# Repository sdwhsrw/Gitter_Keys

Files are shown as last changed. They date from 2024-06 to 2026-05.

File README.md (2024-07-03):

# Warning: The project is still in progress.
# The project code and design files have not yet been organized and uploaded.

# Gitter_Keys
Gitter is an open-source key matrix project. Gitter_Keys is the mechanical keys key version of it. 

Gitter is designed to easy build. 
It uses raspberry pi pico as controller, which you can easily get with 4 to 5 Euros
The smd components are easy to solder even for beginner. 

# BOM

# Building guide
to be continue

79f692e05d4cde133819e3d3e140f79

# Links

https://www.instagram.com/wqnmf2046/

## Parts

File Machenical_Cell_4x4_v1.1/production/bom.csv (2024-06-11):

Designator | Footprint | Quantity | Value | LCSC Part #
D1, D10, D11, D12, D13, D14, D15, D16, D2, D3, D4, D5, D6, D7, D8, D9 | D_MiniMELF | 16 | LL4148
H1, H2, H3, H4 | Moutinghole_M2.5 | 4 | MountingHole
J1, J10, J11, J12, J13, J14, J15, J16, J17, J18, J19, J2, J20, J21, J22, J23, J24, J3, J4, J5, J6, J7, J8, J9 | SolderPad_2 | 24 | Conn_01x02_Pin
J25 | PinHeader_1x06_P2.54mm_Vertical | 1 | Conn_01x06_Pin
K1, K10, K11, K12, K13, K14, K15, K16, K2, K3, K4, K5, K6, K7, K8, K9 | MX-Hotswap-1U-1206-Reserved-LED | 16 | CherryMX_LED
Pico1 | Pico_THR_Necessary | 1 | Pico_Necessary
R1, R10, R11, R12, R13, R14, R15, R16, R2, R3, R4, R5, R6, R7, R8, R9 | 0805 | 16 | LED_Res

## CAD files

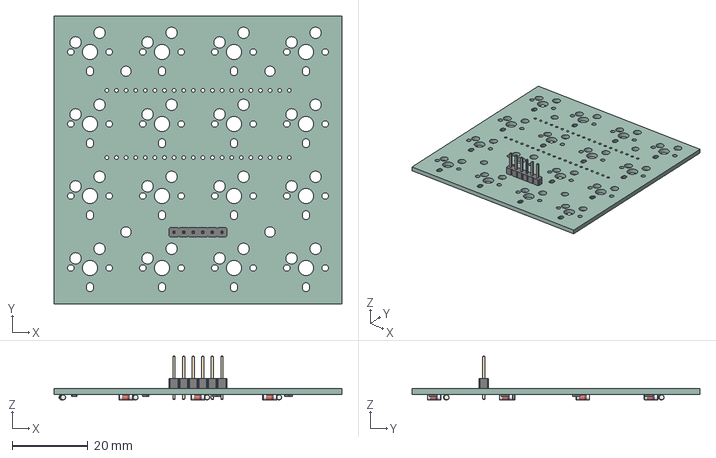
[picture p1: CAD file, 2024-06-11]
Machenical_Cell_4x4_v1.1/Machenical_Cell_4x4_v1.1.step
76.2 x 76.2 x 11.6 mm
_autosave-Machenical_Cell_4x4_v1.1 PCB

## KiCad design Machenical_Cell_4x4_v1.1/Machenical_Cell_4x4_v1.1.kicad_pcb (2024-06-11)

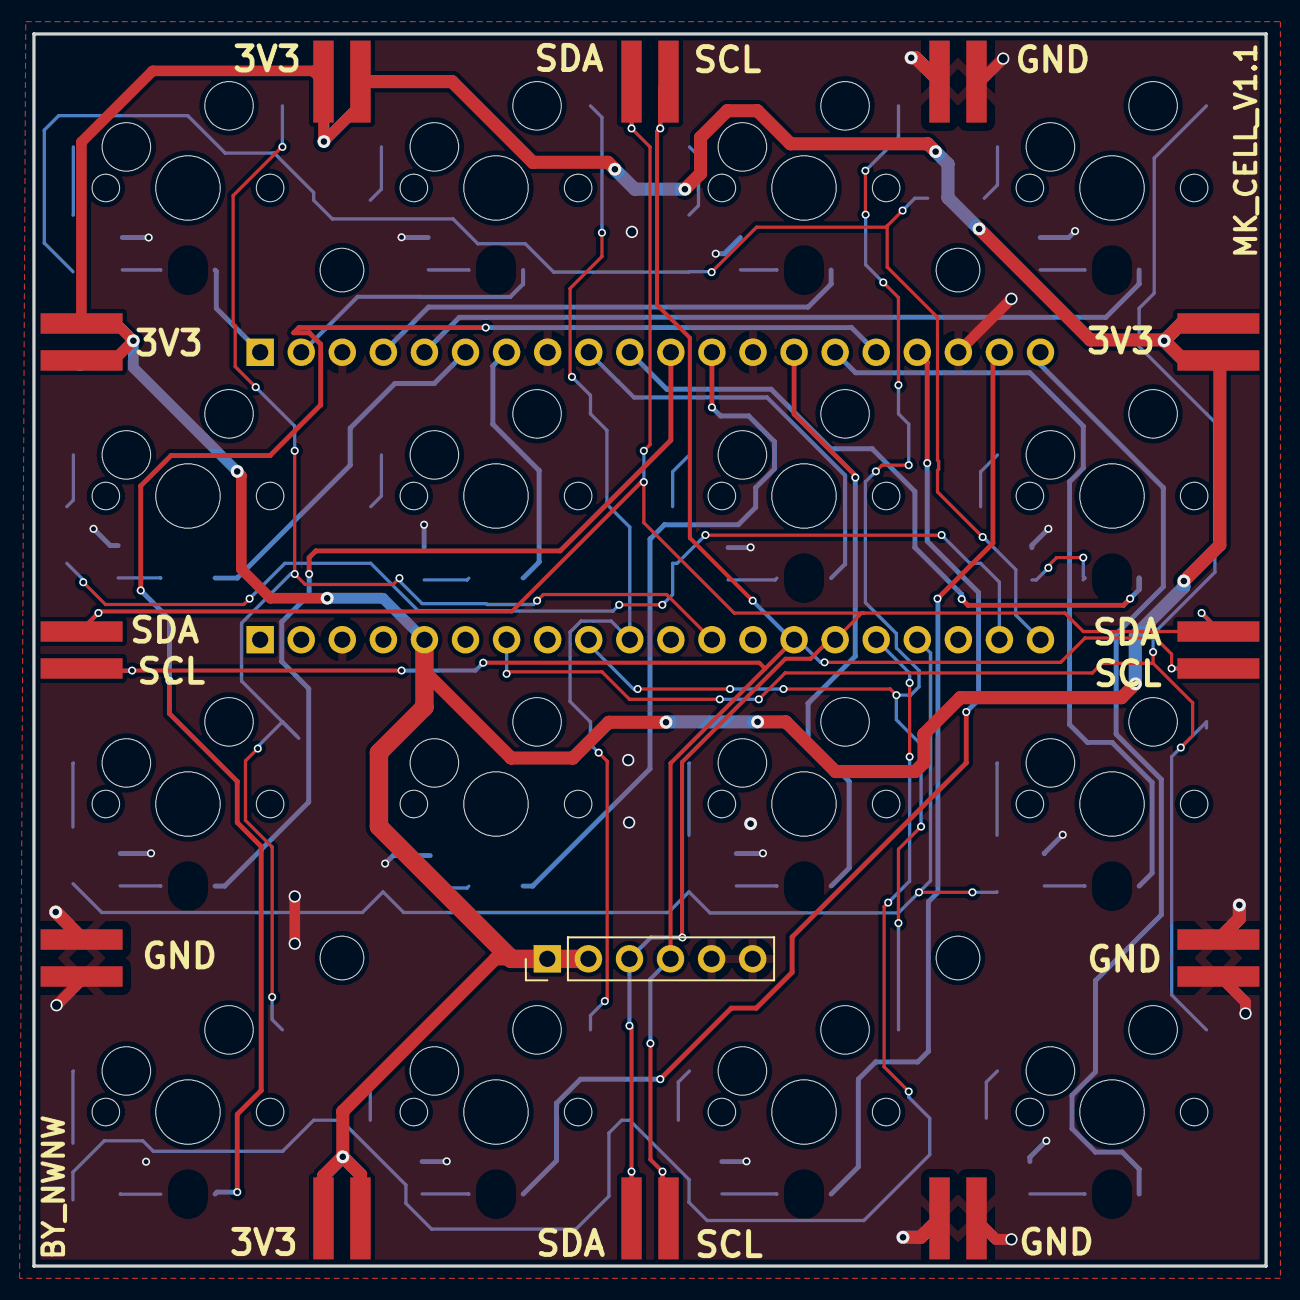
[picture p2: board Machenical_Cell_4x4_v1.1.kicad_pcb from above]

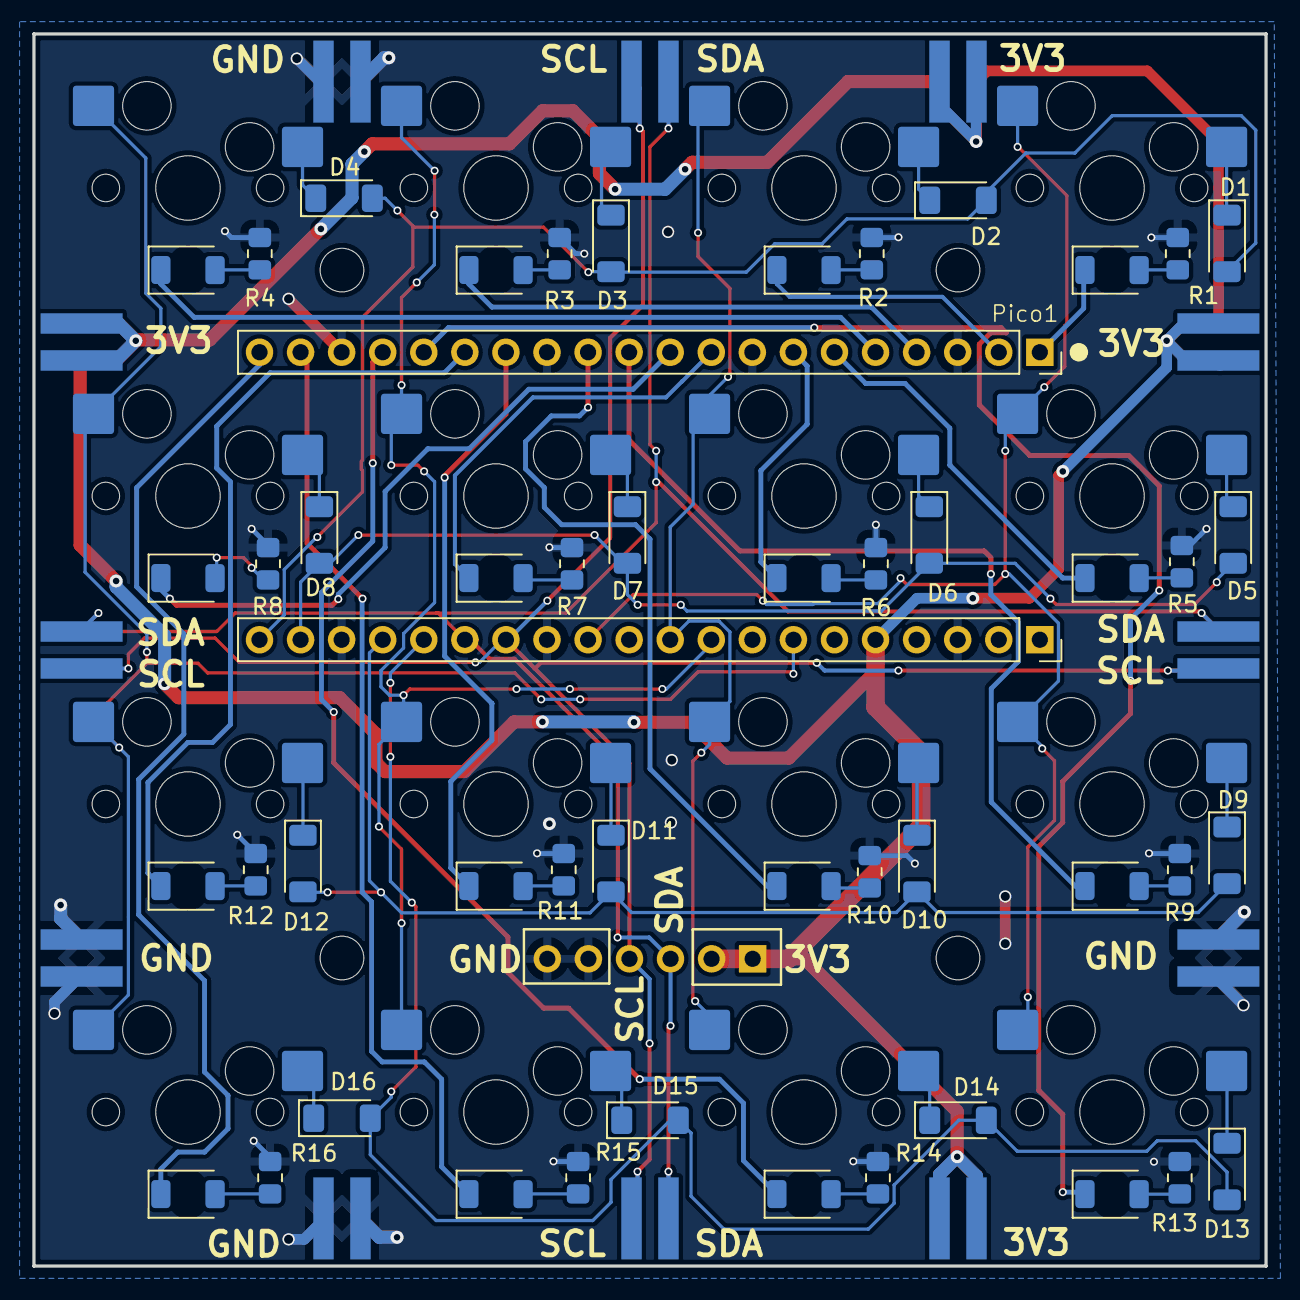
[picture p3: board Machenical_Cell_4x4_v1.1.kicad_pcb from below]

Board: 2 copper layers, 76.2 x 76.2 mm, 78 parts (45 on the bottom side), 60 nets.

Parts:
D1, D2, D3, D4, D5, D6, D7, D8, D9, D10, D11, D12, D13, D14, D15, D16: LL4148; D_MiniMELF
H1, H2, H3, H4: MountingHole; Moutinghole_M2.5
J1, J2, J3, J4, J5, J6, J7, J8, J9, J10, J11, J12, J13, J14, J15, J16, J17, J18, J19, J20, J21, J22, J23, J24: Conn_01x02_Pin; SolderPad_2
J25: Conn_01x06_Pin; PinHeader_1x06_P2.54mm_Vertical
K1, K2, K3, K4, K5, K6, K7, K8, K9, K10, K11, K12, K13, K14, K15, K16: CherryMX_LED; MX-Hotswap-1U-1206-Reserved-LED
Pico1: Pico_Necessary; Pico_THR_Necessary
R1, R2, R3, R4, R5, R6, R7, R8, R9, R10, R11, R12, R13, R14, R15, R16: LED_Res; R_0805_2012Metric_Pad1.20x1.40mm_HandSolder

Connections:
/Col0: K1.2, K5.2, K9.2, K13.2, Pico1.29 (GPIO22)
/Col1: K2.2, K6.2, K10.2, K14.2, Pico1.31 (GPIO26_ADC0)
/Col2: K3.2, K7.2, K11.2, K15.2, Pico1.32 (GPIO27_ADC1)
/Col3: K4.2, K8.2, K12.2, K16.2, Pico1.34 (GPIO28_ADC2)
/LED0: K1.3 (A), Pico1.1 (GPIO0)
/LED1: K2.3 (A), Pico1.2 (GPIO1)
/LED2: K3.3 (A), Pico1.4 (GPIO2)
/LED3: K4.3 (A), Pico1.5 (GPIO3)
/LED10: K5.3 (A), Pico1.6 (GPIO4)
/LED11: K6.3 (A), Pico1.7 (GPIO5)
/LED12: K7.3 (A), Pico1.9 (GPIO6)
/LED13: K8.3 (A), Pico1.10 (GPIO7)
/LED20: K9.3 (A), Pico1.11 (GPIO8)
/LED21: K10.3 (A), Pico1.12 (GPIO9)
/LED22: K11.3 (A), Pico1.14 (GPIO10)
/LED23: K12.3 (A), Pico1.15 (GPIO11)
/LED30: K13.3 (A), Pico1.16 (GPIO12)
/LED31: K14.3 (A), Pico1.17 (GPIO13)
/LED32: K15.3 (A), Pico1.19 (GPIO14)
/LED33: K16.3 (A), Pico1.20 (GPIO15)
/Row0: D1.2 (A), D2.2 (A), D3.2 (A), D4.2 (A), Pico1.21 (GPIO16)
/Row1: D5.2 (A), D6.2 (A), D7.2 (A), D8.2 (A), Pico1.22 (GPIO17)
/Row2: D9.2 (A), D10.2 (A), D11.2 (A), D12.2 (A), Pico1.24 (GPIO18)
/Row3: D13.2 (A), D14.2 (A), D15.2 (A), D16.2 (A), Pico1.25 (GPIO19)
/SCL: J1.2, J4.2, J7.2, J10.2, J13.2, J16.2, J19.2, J22.2, J25.4, Pico1.27 (GPIO21)
/SDA: J1.1, J4.1, J7.1, J10.1, J13.1, J16.1, J19.1, J22.1, J25.3, Pico1.26 (GPIO20)
GND: J2.1, J2.2, J3.1, J3.2, J8.1, J8.2, J9.1, J9.2, J11.1, J11.2, J12.1, J12.2, J17.1, J17.2, J18.1, J18.2, J25.5, J25.6, Pico1.3 (GND), Pico1.8 (GND), Pico1.13 (GND), Pico1.18 (GND), Pico1.23 (GND), Pico1.28 (GND), Pico1.38 (GND), R1.1, R2.1, R3.1, R4.1, R5.1, R6.1, R7.1, R8.1, R9.1, R10.1, R11.1, R12.1, R13.1, R14.1, R15.1, R16.1
unnamed: D1.1 (K), K1.1
unnamed: D2.1 (K), K2.1
unnamed: D3.1 (K), K3.1
unnamed: D4.1 (K), K4.1
unnamed: D5.1 (K), K5.1
unnamed: D6.1 (K), K6.1
unnamed: D7.1 (K), K7.1
unnamed: D8.1 (K), K8.1
unnamed: D9.1 (K), K9.1
unnamed: D10.1 (K), K10.1
unnamed: D11.1 (K), K11.1
unnamed: D12.1 (K), K12.1
unnamed: D13.1 (K), K13.1
unnamed: D14.1 (K), K14.1
unnamed: D15.1 (K), K15.1
unnamed: D16.1 (K), K16.1
unnamed: K1.4 (K), R1.2
unnamed: K2.4 (K), R2.2
unnamed: K3.4 (K), R3.2
unnamed: K4.4 (K), R4.2
unnamed: K5.4 (K), R5.2
unnamed: K6.4 (K), R6.2
unnamed: K7.4 (K), R7.2
unnamed: K8.4 (K), R8.2
unnamed: K9.4 (K), R9.2
unnamed: K10.4 (K), R10.2
unnamed: K11.4 (K), R11.2
unnamed: K12.4 (K), R12.2
unnamed: K13.4 (K), R13.2
unnamed: K14.4 (K), R14.2
unnamed: K15.4 (K), R15.2
unnamed: K16.4 (K), R16.2
VCC: J5.1, J5.2, J6.1, J6.2, J14.1, J14.2, J15.1, J15.2, J20.1, J20.2, J21.1, J21.2, J23.1, J23.2, J24.1, J24.2, J25.1, J25.2, Pico1.36 (3V3)

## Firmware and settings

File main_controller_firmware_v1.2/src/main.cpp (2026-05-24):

#include <Arduino.h>
#include <Wire.h>
#include <elapsedMillis.h>
#include <tusb.h>

#include "Grid.h"
#include "Cell.h"
#include "MonomeSerialDevice.h"

// usb config 
#include "custom_tusb_config.h"

#define I2C_SDA 8
#define I2C_SCL 9

void sendLeds();

const uint8_t gammaTable[16] = { 0, 2, 3, 6, 11, 18, 25, 32, 41, 59, 70, 80, 92, 103, 115, 128 };

bool isInited = false;
elapsedMillis monomeRefresh; // timer

// set your monome device name here
String deviceID = "neo-monome";
String serialNum = "m4216124";

// Led / Cell Info
constexpr uint8_t ledRows = 8;
constexpr uint8_t ledCols = 8;
constexpr uint8_t cellSize = 4;
constexpr uint8_t cellRows = ledRows / cellSize;
constexpr uint8_t cellCols = ledCols / cellSize;
constexpr uint16_t ledNum = ledRows * ledCols;
constexpr uint16_t cellNum = cellRows * cellCols;

// Monome class setup
MonomeSerialDevice mdp;
Cell cells[cellRows][cellCols] = {{Cell(0x01, &Wire), Cell(0x02, &Wire)},
                                  {Cell(0x03, &Wire), Cell(0x04, &Wire)}};
Grid g1((Cell *)cells, cellCols, cellRows); 

int prevLedBuffer[ledNum];



void setup() 
{
  // I2C setup  
  Wire.setSDA(I2C_SDA);
  Wire.setSCL(I2C_SCL);
  Wire.begin();
  // Initialize each cell and check if it's there
  for (int i=0; i<cellRows; i++)
  {
    for (int j=0; j<cellCols; j++)
    {
      cells[i][j].begin();
    }
  }

  // USB Setup

  tud_init(BOARD_TUD_RHPORT);

  mdp.isMonome = true;
  mdp.deviceID = deviceID;
  mdp.setupAsGrid(ledRows, ledCols);
  monomeRefresh = 0; //elapsedMillis对象 重置计时器
  isInited = true;

  int var = 0;
  //? wait for ready ?
  while (var < 8) 
  {
    tud_task(); //? for what ? 
    mdp.poll();
    var++;
    delay(100);
  }

  // Serial.println("set up finished");

  // test and reset
  mdp.setAllLEDs(15);
  sendLeds();
  delay(500);
  mdp.setAllLEDs(0);
  sendLeds();

  g1.vSetAllLedOn();
  delay(500);
  g1.vSetAllLedOff();
  delay(500);
}

void loop() 
{
  tud_task();
  mdp.poll();

  if (isInited && monomeRefresh > 16)
  {
    g1.vGetGridKey();
    g1.vSendGridKey();
    sendLeds();
    monomeRefresh = 0;
  }
}

void sendLeds()
{
  uint8_t value, prevValue = 0;
  // bool updateFlag = false;
  for (int i = 0; i < ledNum; i++)
  {
    value = mdp.leds[i];
    prevValue = prevLedBuffer[i];
    
    if (value != prevValue)
    {
      g1.vSetGridLed(i, gammaTable[value]);
      prevLedBuffer[i] = value;
      // updateFlag = true;
    }
  }
  g1.vUpdateGridLed();
}

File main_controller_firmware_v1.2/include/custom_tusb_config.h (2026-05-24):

#ifndef _TUSB_CONFIG_H_
#define _TUSB_CONFIG_H_

#ifdef __cplusplus
 extern "C" {
#endif

// about port number.. rp2040 seems only 1 so zero here
// RHPort number used for device can be defined by board.mk, default to port 0
#ifndef BOARD_TUD_RHPORT
#define BOARD_TUD_RHPORT      0
#endif

// Speed configaration
// RHPort max operational speed can defined by board.mk
#ifndef BOARD_TUD_MAX_SPEED
#define BOARD_TUD_MAX_SPEED   OPT_MODE_DEFAULT_SPEED
#endif

//--------------------------------------------------------------------
// COMMON CONFIGURATION
//--------------------------------------------------------------------


// defined by board.mk
#ifndef CFG_TUSB_MCU
  #error CFG_TUSB_MCU must be defined
#endif

#ifndef CFG_TUSB_OS
  #define CFG_TUSB_OS               OPT_OS_NONE
#endif

#ifndef CFG_TUSB_DEBUG
 #define CFG_TUSB_DEBUG 0
#endif


// ------------------------------NO IDEA WHAT IS THIS
// Enable Device stack
#define CFG_TUD_ENABLED       1

// Default is max speed that hardware controller could support with on-chip PHY
#define CFG_TUD_MAX_SPEED     BOARD_TUD_MAX_SPEED


// some memory shit ...

/* USB DMA on some MCUs can only access a specific SRAM region with restriction on alignment.
 * Tinyusb use follows macros to declare transferring memory so that they can be put
 * into those specific section.
 * e.g
 * - CFG_TUSB_MEM SECTION : __attribute__ (( section(".usb_ram") ))
 * - CFG_TUSB_MEM_ALIGN   : __attribute__ ((aligned(4)))
 */
#ifndef CFG_TUSB_MEM_SECTION
#define CFG_TUSB_MEM_SECTION
#endif

#ifndef CFG_TUSB_MEM_ALIGN
#define CFG_TUSB_MEM_ALIGN    __attribute__ ((aligned(4)))
#endif


//--------------------------------------------------------------------
// DEVICE CONFIGURATION
//--------------------------------------------------------------------

#ifndef CFG_TUD_ENDPOINT0_SIZE
#define CFG_TUD_ENDPOINT0_SIZE    64
#endif

#define CFG_TUD_DESC_USE_HW 0

//------------- CLASS -------------//
#define CFG_TUD_CDC              1  // CDC what we need 
#define CFG_TUD_MSC              0  // Mass Storage Class (MSC)
#define CFG_TUD_HID              0
#define CFG_TUD_MIDI             0
#define CFG_TUD_VENDOR           0


// CDC FIFO size of TX and RX
#define CFG_TUD_CDC_RX_BUFSIZE   (TUD_OPT_HIGH_SPEED ? 512 : 64)
#define CFG_TUD_CDC_TX_BUFSIZE   (TUD_OPT_HIGH_SPEED ? 512 : 64)

// CDC Endpoint transfer buffer size, more is faster
#define CFG_TUD_CDC_EP_BUFSIZE   (TUD_OPT_HIGH_SPEED ? 512 : 64)


#ifdef __cplusplus
 }
#endif

//--------------------------------------------------------------------
// MODIFY
//--------------------------------------------------------------------
#define TUD_CDC_DESCRIPTOR_MONOME(_itfnum, _stridx, _ep_notif, _ep_notif_size, _epout, _epin, _epsize) \
  /* Interface Associate */\
  8, TUSB_DESC_INTERFACE_ASSOCIATION, _itfnum, 2, TUSB_CLASS_CDC, CDC_COMM_SUBCLASS_ABSTRACT_CONTROL_MODEL, CDC_COMM_PROTOCOL_NONE, 0,\
  /* CDC Control Interface */\
  9, TUSB_DESC_INTERFACE, _itfnum, 0, 1, TUSB_CLASS_CDC, CDC_COMM_SUBCLASS_ABSTRACT_CONTROL_MODEL, CDC_COMM_PROTOCOL_NONE, _stridx,\
  /* CDC Header */\
  5, TUSB_DESC_CS_INTERFACE, CDC_FUNC_DESC_HEADER, U16_TO_U8S_LE(0x0120),\
  /* CDC Call Management */\
  5, TUSB_DESC_CS_INTERFACE, CDC_FUNC_DESC_CALL_MANAGEMENT, 0x02, (uint8_t)((_itfnum) + 1),\
  /* CDC ACM */\
  4, TUSB_DESC_CS_INTERFACE, CDC_FUNC_DESC_ABSTRACT_CONTROL_MANAGEMENT, 2,\
  /* CDC Union */\
  5, TUSB_DESC_CS_INTERFACE, CDC_FUNC_DESC_UNION, _itfnum, (uint8_t)((_itfnum) + 1),\
  /* Endpoint Notification */\
  7, TUSB_DESC_ENDPOINT, _ep_notif, TUSB_XFER_INTERRUPT, U16_TO_U8S_LE(_ep_notif_size), 16,\
  /* CDC Data Interface */\
  9, TUSB_DESC_INTERFACE, (uint8_t)((_itfnum) + 1), 0, 2, TUSB_CLASS_CDC_DATA, 0, 0, 0,\
  /* Endpoint OUT */\
  7, TUSB_DESC_ENDPOINT, _epout, TUSB_XFER_BULK, U16_TO_U8S_LE(_epsize), 0,\
  /* Endpoint IN */\
  7, TUSB_DESC_ENDPOINT, _epin, TUSB_XFER_BULK, U16_TO_U8S_LE(_epsize), 0

#endif /* _TUSB_CONFIG_H_ */

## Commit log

2026-05-24 Firmware Version V1.2
    setup raw tinyusb, fix configuration descriptor endpoint mapping
    improve i2c robustness
    improve code format
    [Cell.cpp, MonomeSerialDevice.cpp, custom_tusb_config.h]
2026-06-15 git ignore kicad backup folder
